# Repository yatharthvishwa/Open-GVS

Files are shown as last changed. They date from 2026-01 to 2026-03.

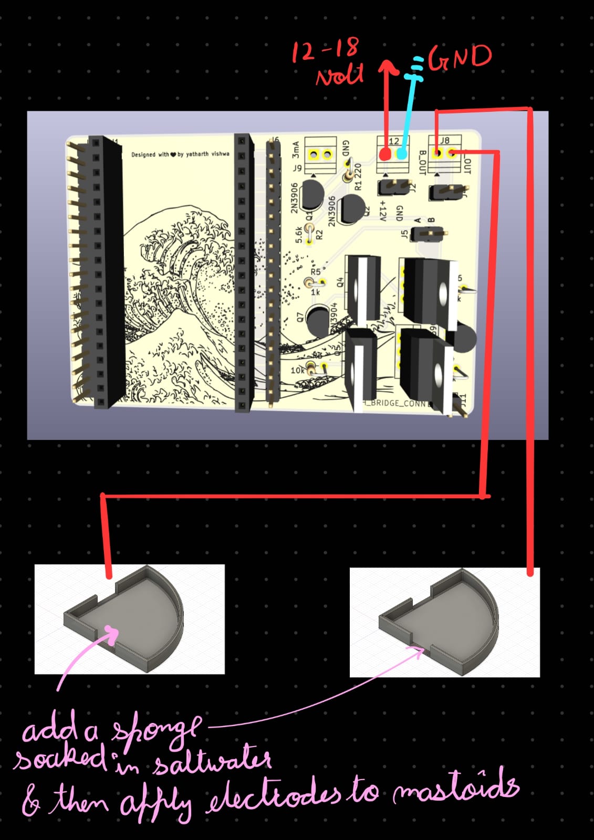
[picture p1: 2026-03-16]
wiring_diagram/wiringdiagram.jpeg

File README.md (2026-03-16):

# Open-GVS
control a person with gvs!!
this can control your balance by applying a controlled current to your mastoids, this project uses diy 3d printed electrodes which you can apply to your mastoids which are connected to the pcb
I was inspired to make this project because of a open sauce video https://www.youtube.com/watch?v=9Om2X6QcTgw

how to use?
here is the wiring diagram

📄 [View BOM](./GVS.csv)

electrode stl
Electrode

PCB
PCB

Simulation
Simulation

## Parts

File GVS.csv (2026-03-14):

Qty | Value | Description | UNIT Price inr | value inr | Value usd | notes | URL
1 | Conn_01x19_Socket | female pin header | 9 | 9 | 0.099 | could only find 40 | https://quartzcomponents.com/products/40-pin-straight-female-berg-strips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
1 | Conn_01x02_Pin | male pin header | 7 | 7 | 0.077 | could only find 40 | https://quartzcomponents.com/products/40-pin-break-away-headers-straight-male-headers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
1 | Conn_01x19_Pin | male pin header | 7 | 7 | 0.077 | could only find 40
3 | Screw_Terminal_01x02 | screw terminal | 16.12 | 48.36 | 0.53196 |  | https://sharvielectronics.com/product/xy308-2-54mm-2-pin-screw-terminal-block/
5 | 2N3906 | bjt pnp | 3.42 | 17.1 | 0.1881 | minimun order 5 | https://sharvielectronics.com/product/2n3906-pnp-general-purpose-transistor-40v-200ma-to-92-package/
2 | IRF9540N | p channel mosfet | 39.85 | 79.7 | 0.8767 |  | https://sharvielectronics.com/product/irf9540n-100v-23a-p-channel-power-mosfet-to-220-package/
2 | IRLZ44N | n channel mosfet | 24.75 | 49.5 | 0.5445 |  | https://sharvielectronics.com/product/irfz44npbf-n-channel-mosfet-to-220-package/
5 | 2N3904 | bjt npn | 3.59 | 17.95 | 0.19745 | minimun order 5 | https://sharvielectronics.com/product/2n3904-npn-general-purpose-transistor-40v-200ma-to-92-package/
1 | 220 | resistor | 1.75 | 1.75 | 0.01925 |  | https://sharvielectronics.com/product/220-ohm-1-4-watt-resistor-1-tolerance/
1 | 5.6k | resistor | 0.45 | 0.45 | 0.00495 |  | https://sharvielectronics.com/product/5-6k-ohm-1-4-watt-resistor-5-tolerance/
1 | 10k | resistor | 6 | 6 | 0.066 |  | https://quartzcomponents.com/products/10k-ohm-1-4-watt-resistor-with-1-tolerance-pack-of-10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
1 | 1k | resistor | 5 | 5 | 0.055 |  | https://quartzcomponents.com/products/1k-ohm-1-4-watt-resistor?_pos=3&_sid=f0155496c&_ss=r
2 | 4xAA battery holder | AA battery holder | 64.63 | 129.26 | 1.42186 |  | https://sharvielectronics.com/product/4xaa-battery-holder-with-cover-and-on-off-switch/
1 | ESP32 WROOM | ESP32 | 455.77 | 455.77 | 5.01347 |  | https://sharvielectronics.com/product/esp32-wroom-32-wifi-bluetooth-development-board-with-cp2102-type-c-connector/
 | PCB | PCB | 181.45 | 181.45 | 1.99595
 | PCB shipping | pcb shipping | 739.39 | 739.39 | 8.13329
 |  |  |  | 0 | 0
 |  |  |  | 0 | 0
 | SHIPPING |  | 125 | 125 | 1.375
 | taxes |  | 171.71 | 171.71 | 1.88881
 |  |  |  |  | 0
 | total |  |  | 2051.39 | 22.56529

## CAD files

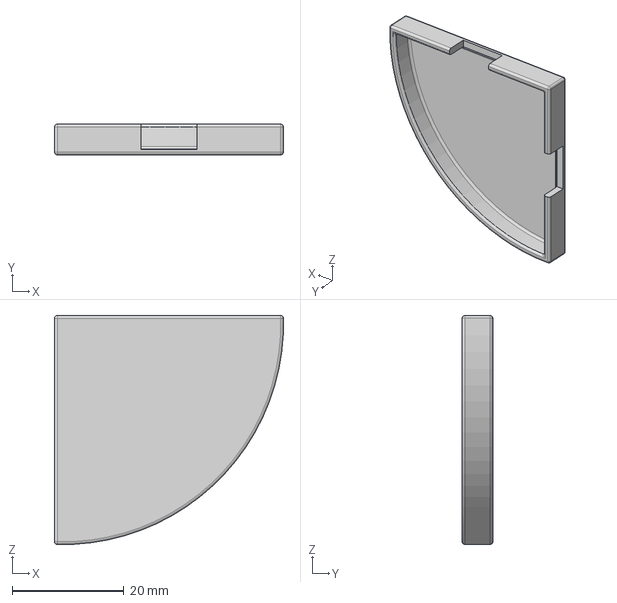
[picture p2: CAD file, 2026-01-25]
Model/electrode case.step
41.0 x 5.50 x 41.0 mm

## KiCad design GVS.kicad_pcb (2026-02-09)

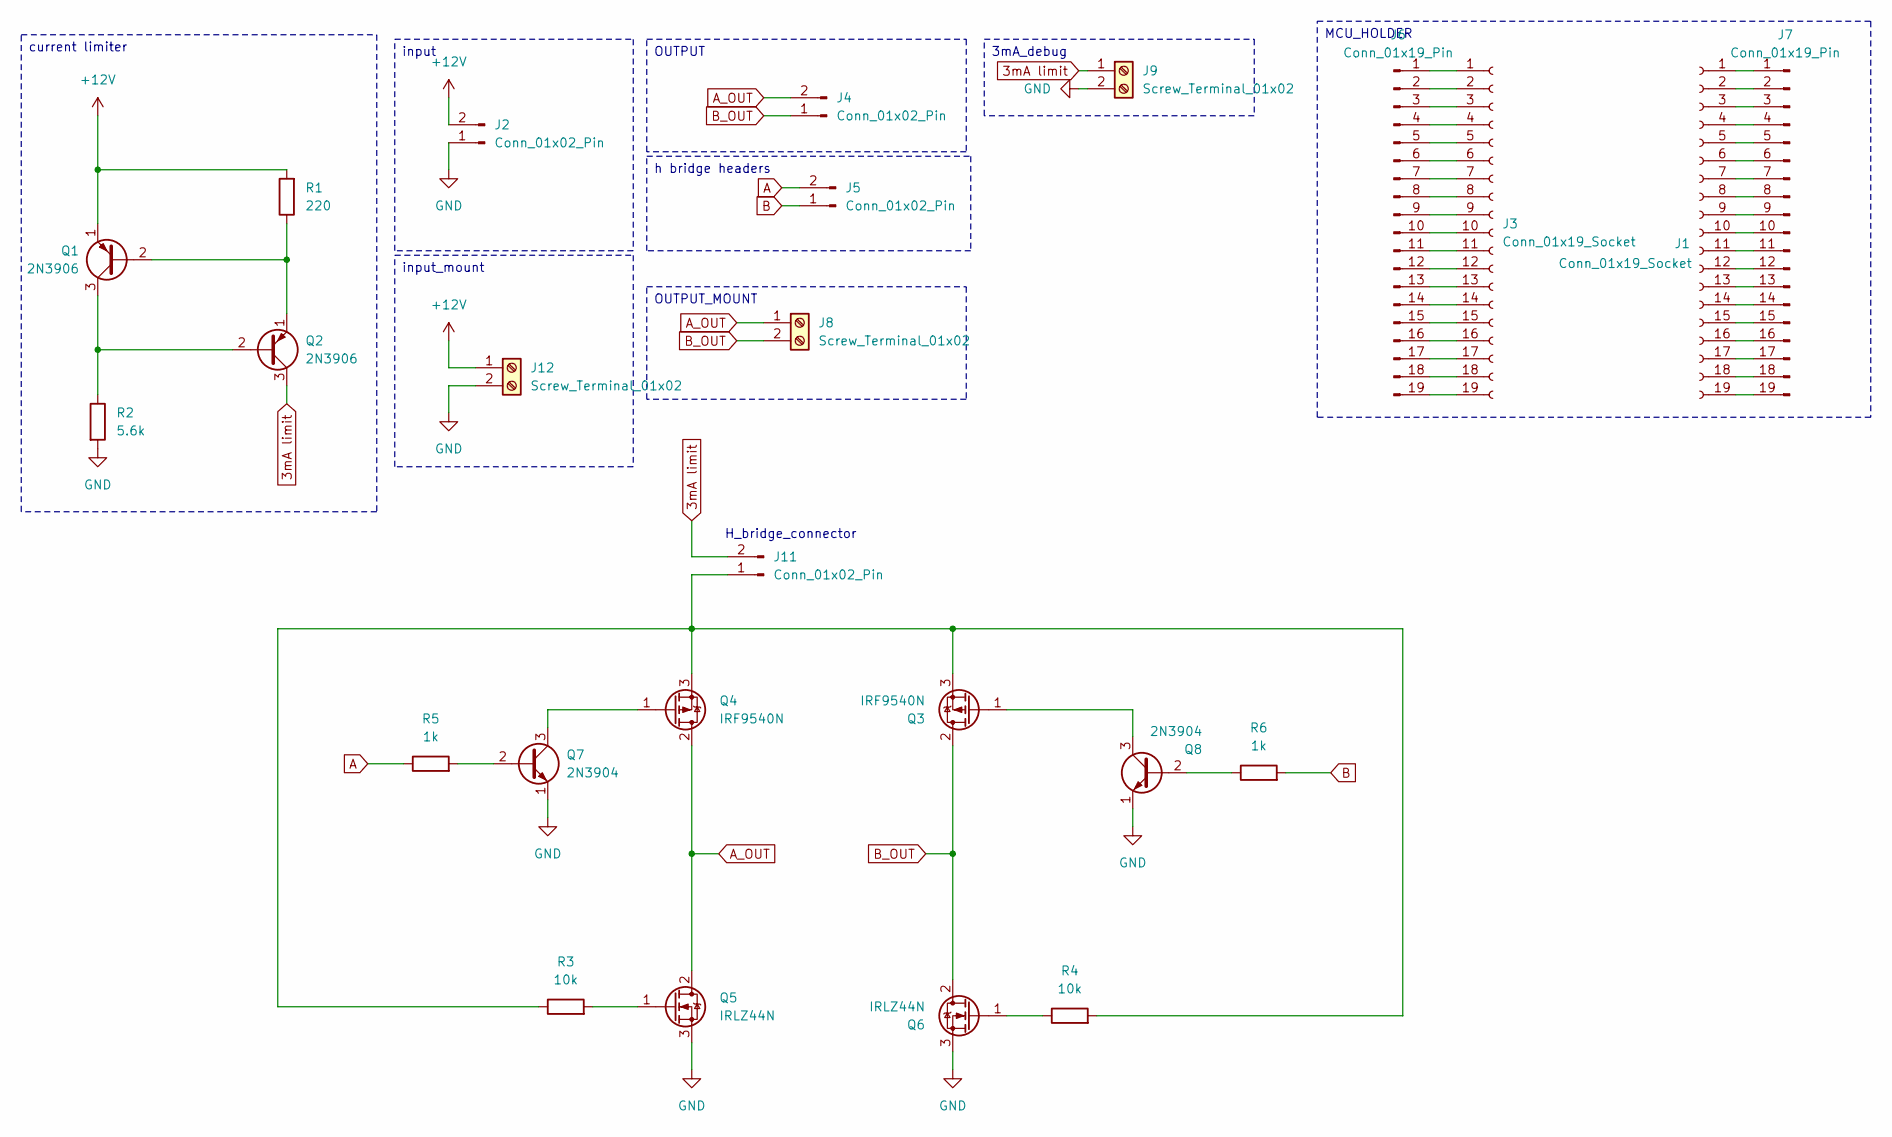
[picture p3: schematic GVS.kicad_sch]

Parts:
J1, J3: Conn_01x19_Socket; PinSocket_1x19_P2.54mm_Vertical
J2, J4, J5, J11: Conn_01x02_Pin; PinHeader_1x02_P2.54mm_Vertical
J6, J7: Conn_01x19_Pin; PinHeader_1x19_P2.54mm_Vertical
J8, J9, J12: Screw_Terminal_01x02; TerminalBlock_Xinya_XY308-2.54-2P_1x02_P2.54mm_Horizontal
Q1, Q2: 2N3906; TO-92_Inline
Q3, Q4: IRF9540N; TO-220-3_Vertical
Q5, Q6: IRLZ44N; TO-220-3_Vertical
Q7, Q8: 2N3904; TO-92_Inline
R1: 220; R_Axial_DIN0204_L3.6mm_D1.6mm_P2.54mm_Vertical
R2: 5.6k; R_Axial_DIN0204_L3.6mm_D1.6mm_P2.54mm_Vertical
R3, R4: 10k; R_Axial_DIN0204_L3.6mm_D1.6mm_P2.54mm_Vertical
R5, R6: 1k; R_Axial_DIN0204_L3.6mm_D1.6mm_P2.54mm_Vertical

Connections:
3mA limit: J9.1, J11.2, Q2.3 (C)
+12V: J2.2, J12.1, Q1.1 (E), R1.2
A: J5.2, R5.1
A_OUT: J4.2, J8.1, Q4.2 (D), Q5.2 (D)
B: J5.1, R6.2
B_OUT: J4.1, J8.2, Q3.2 (D), Q6.2 (D)
GND: J2.1, J9.2, J12.2, Q5.3 (S), Q6.3 (S), Q7.1 (E), Q8.1 (E), R2.2
unnamed: J1.1, J7.1
unnamed: J1.2, J7.2
unnamed: J1.3, J7.3
unnamed: J1.4, J7.4
unnamed: J1.5, J7.5
unnamed: J1.6, J7.6
unnamed: J1.7, J7.7
unnamed: J1.8, J7.8
unnamed: J1.9, J7.9
unnamed: J1.10, J7.10
unnamed: J1.11, J7.11
unnamed: J1.12, J7.12
unnamed: J1.13, J7.13
unnamed: J1.14, J7.14
unnamed: J1.15, J7.15
unnamed: J1.16, J7.16
unnamed: J1.17, J7.17
unnamed: J1.18, J7.18
unnamed: J1.19, J7.19
unnamed: J3.1, J6.1
unnamed: J3.2, J6.2
unnamed: J3.3, J6.3
unnamed: J3.4, J6.4
unnamed: J3.5, J6.5
unnamed: J3.6, J6.6
unnamed: J3.7, J6.7
unnamed: J3.8, J6.8
unnamed: J3.9, J6.9
unnamed: J3.10, J6.10
unnamed: J3.11, J6.11
unnamed: J3.12, J6.12
unnamed: J3.13, J6.13
unnamed: J3.14, J6.14
unnamed: J3.15, J6.15
unnamed: J3.16, J6.16
unnamed: J3.17, J6.17
unnamed: J3.18, J6.18
unnamed: J3.19, J6.19
unnamed: J11.1, Q3.3 (S), Q4.3 (S), R3.1, R4.2
unnamed: Q1.2 (B), Q2.1 (E), R1.1
unnamed: Q1.3 (C), Q2.2 (B), R2.1
unnamed: Q3.1 (G), Q8.3 (C)
unnamed: Q4.1 (G), Q7.3 (C)
unnamed: Q5.1 (G), R3.2
unnamed: Q6.1 (G), R4.1
unnamed: Q7.2 (B), R5.2
unnamed: Q8.2 (B), R6.1

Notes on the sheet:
H_bridge_connector
input_mount
3mA_debug
MCU_HOLDER
input
OUTPUT_MOUNT
h bridge headers
current limiter
OUTPUT

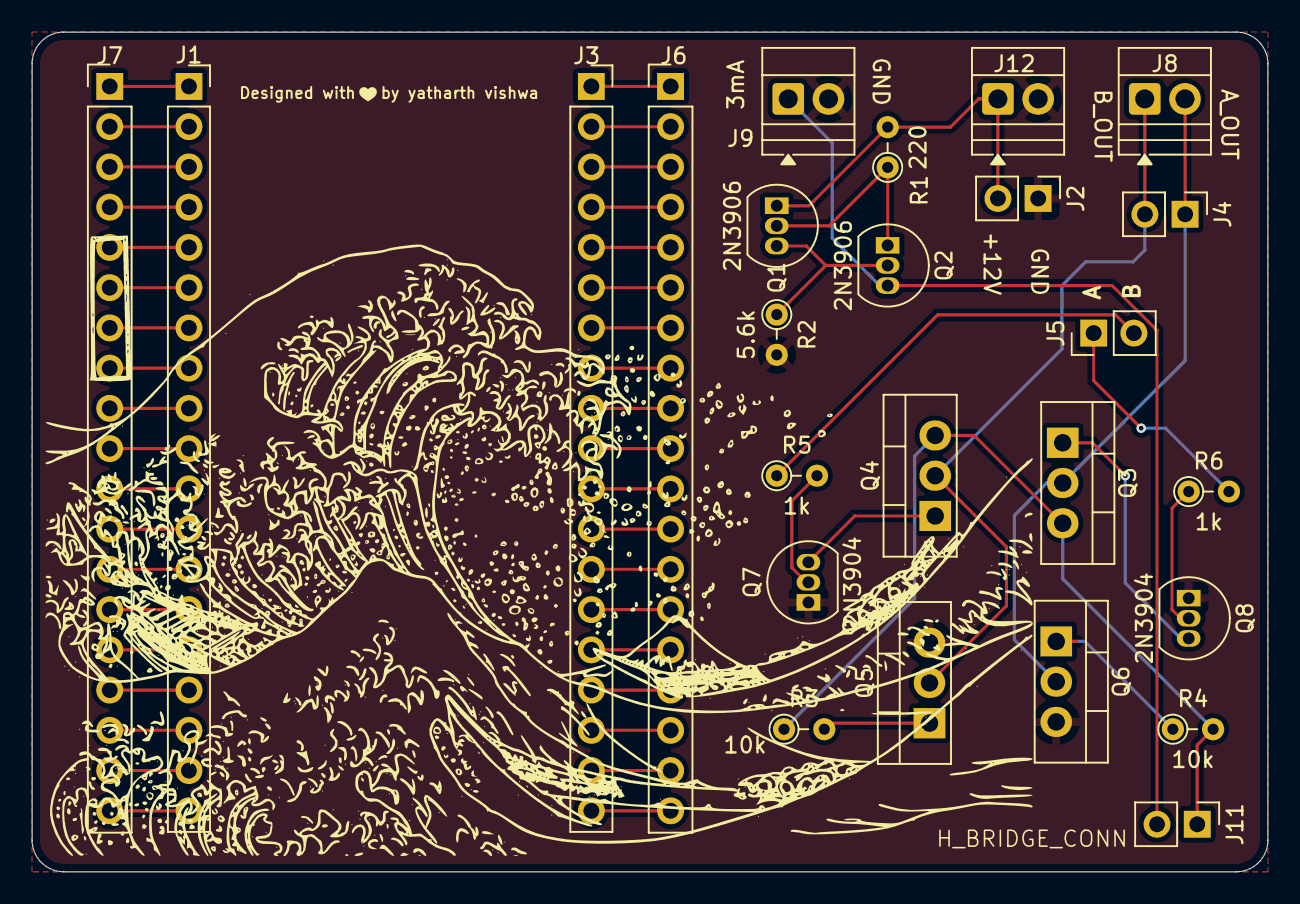
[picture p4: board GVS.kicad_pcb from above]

Board: 2 copper layers, 78.0 x 53.0 mm, 25 parts (0 on the bottom side), 54 nets.

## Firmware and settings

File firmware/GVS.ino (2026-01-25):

#include "BluetoothSerial.h"

BluetoothSerial SerialBT;


void setup() {
  pinMode(12, OUTPUT);
  pinMode(14, OUTPUT);

  Serial.begin(115200);

  SerialBT.begin("ESP32_RAHHHHHHHHHH"); // Bluetooth name
  Serial.println("Bluetooth started. Pair with ESP32_Blinky");
}

void loop() {
  if (SerialBT.available()) {
    char cmd = SerialBT.read();

    if (cmd == '1')

    {
      digitalWrite(12, HIGH);
      digitalWrite(14, LOW);
      SerialBT.println("RIGHT");
      SerialBT.println("12_HIGH 14_LOW");
    }


    else if (cmd == '0')

    {
      digitalWrite(14, HIGH);
      digitalWrite(12, LOW);
      SerialBT.println("LEFT");
      SerialBT.println("14_HIGH 12_LOW");
    }


    else if (cmd == '3')

    {
      digitalWrite(14, HIGH);
      digitalWrite(12, HIGH);
      SerialBT.println("STOP");
      SerialBT.println("12_HIGH 14_HIGH");
    }
  }
}

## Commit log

2026-01-25 inital commit
    [GVS.kicad_pcb, GVS.kicad_sch]
2026-01-25 added step files
    [electrode case.step]
2026-02-09 added screw terminals
    [GVS.kicad_pcb, GVS.kicad_sch]
2026-03-14 added BOM
2026-03-14 Update README to link to BOM and remove entries
    Removed detailed BOM entries and added a link to the BOM file.
2026-03-16 Rename Screenshot 2026-01-23 223440.png to Electrode
2026-03-16 Rename Screenshot 2026-02-09 174815.png to PCB
2026-03-16 Fix image link for Electrode in README
2026-03-16 Add images for electrode, PCB, and simulation
